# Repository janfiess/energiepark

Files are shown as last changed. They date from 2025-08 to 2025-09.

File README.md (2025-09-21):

# Energiepark Grischa

## Kopfhörerstationen

### MC -> TouchDesigner

Play/pause Audio 

* MQTT Topic: holz/player/audio/1     Payload: play oder pause
* MQTT Topic: holz/player/audio/2     Payload: play oder pause
* MQTT Topic: holz/player/audio/3     Payload: play oder pause
* MQTT Topic: holz/player/audio/4     Payload: play oder pause
* MQTT Topic: holz/player/audio/5     Payload: play oder pause
* MQTT Topic: holz/player/audio/6     Payload: play oder pause

TouchDesigner -> MC

### Drive LED-Ring sections (12 LEDs):

* MQTT Topic: holz/ledring/numsections/1     Payload: 0 - 12
* MQTT Topic: holz/ledring/numsections/2     Payload: 0 - 12
* MQTT Topic: holz/ledring/numsections/3     Payload: 0 - 12
* MQTT Topic: holz/ledring/numsections/4     Payload: 0 - 12
* MQTT Topic: holz/ledring/numsections/5     Payload: 0 - 12
* MQTT Topic: holz/ledring/numsections/6     Payload: 0 - 12

Notification when track ended, wenn der Kopfhörer eingehängt wurde (denn RFID Tag erkannt wurde):

* MQTT Topic:  ledring/state/1          Payload: leds_idle
* MQTT Topic:  ledring/state/2          Payload: leds_idle
* MQTT Topic:  ledring/state/3          Payload: leds_idle
* MQTT Topic:  ledring/state/4          Payload: leds_idle
* MQTT Topic:  ledring/state/5          Payload: leds_idle
* MQTT Topic:  ledring/state/6          Payload: leds_idle

RFID Tags:
Jeder Kopfhörer ist mit 3 RFID Tags ausgestattet. Mindestens einer muss erkannt werden.

Kopfhörer 1:
* 14AA77D6 (K1A)
* A44347D0 (K1B)
* ....

Kopfhörer 2:
* 241A5FD6 (K2A)
* F40735D6 (K2B)
* ...

Kopfhörer 3:
* 94326BD6 (K3A)
* 271652FA (K3B)
* ...

Kopfhörer 4:
* 74A06BD6 (K4A)
* 27E655FA (K4B)
* ...

Kopfhörer 5:
* 747E6AD6 (K5A) 
* 477251FA (K5B)
* ...

Kopfhörer 6:
* C4B86DD6 (K6A)
* D7091DFA (K6B)
* ...

## RFID-Scan-Station

### MQTT: MC -> TouchDesigner

Topic: holz/rfid     Payload: [id]

### RFID Tags:

Objekt 1 (Kohle klein):
* A5377800 (S1A)
* 1B047A00 (S1B)

Objekt 2 (Kohle gross):
* 57DD7900 (S2A)
* FA9B7800 (S2B)

Objekt 3 (Heizöl):
* 01107B00 (S3A)
* C6937A00 (S3B)

Objekt 4 (Holz):
* 67BC7A00 (S4A)
* E5BA7800 (S4B)

Objekt 5 (tbd):
* 492F7A00 (S5A)
* 35727D00 (S5B)

## LED-Strip

Bespielung via Art-Net.
Adresse LED-Controller (ebenfalls im Switch-Netzwerk): 	192.168.50.195

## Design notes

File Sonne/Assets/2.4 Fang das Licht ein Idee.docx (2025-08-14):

# 2.4 Fang das Licht ein – interaktive Station

Ausgangslage:

PV-Panel:

Grösse PV-Panel: 120cm x 55 cm = 0,66 m²

Strahlungsstärke: 1000 W/m^2

Wirkungsgrad: 20 %

Formel: Stärke x Grösse x Wirkungsgrad x Zeit (h) = Strom

1000 x 0.66 x 0.2 x 1h = 0.132 kWh (Maximum)

💡 LED Lampe 5 Watt für 470 lm

Frage:

Wie lange kann eine LED-Lampe brennen, wenn die Sonne 1 Stunde bei aktueller Neigung des PV-Panels Licht einfängt?

Auf der Grafik verändern sich die Anzeige immer interaktiv zur Bewegung des Panels:

1 aktuelle Stromproduktion
2 Effizienz
3 Farbige Skala
4 Anzahl Stunden

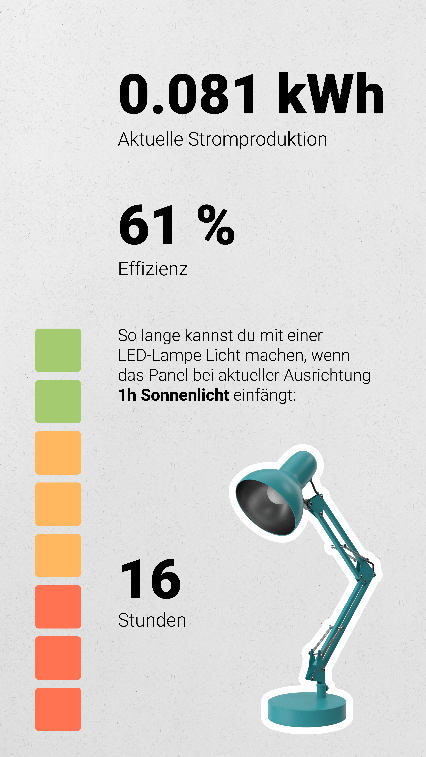
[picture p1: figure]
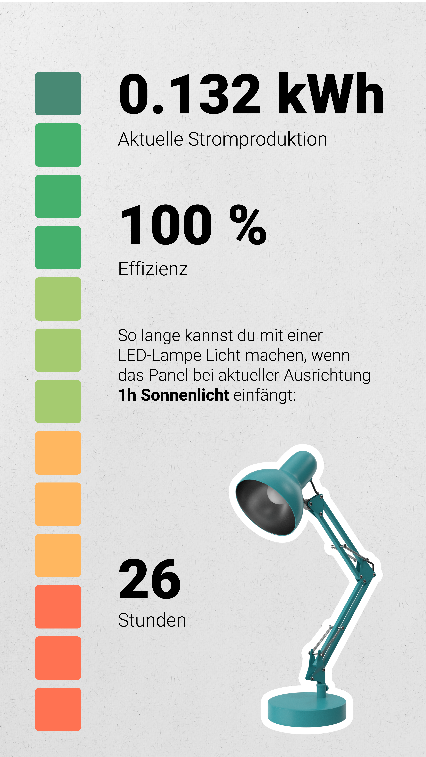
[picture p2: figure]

Grafik 1:

Anzeige bei mittel optimaler Ausrichtung des PV-Panels

Grafik 2:

Anzeige, bei perfekter Ausrichtung des PV-Panels

Abstufungen der Skala

kWh Stunden

0.010 2

0.020 4

0.030 6

0.040 8

0.050 10

0.060 12

0.070 14

0.080 16

0.090 18

0.100 20

0.110 22

0.120 24

0.130 26

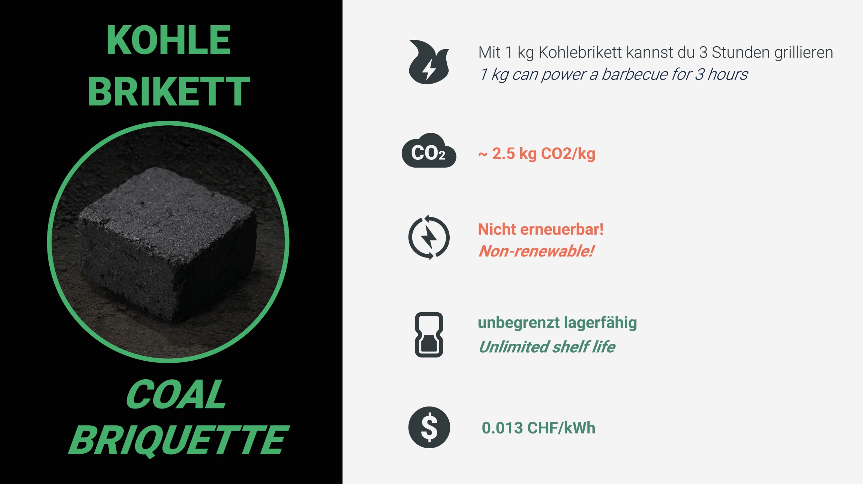
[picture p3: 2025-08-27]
Holz/Assets/RFID-Scanner Watt steckt da drin/1.2_Watt_steckt_da_drin-Kohle.jpeg

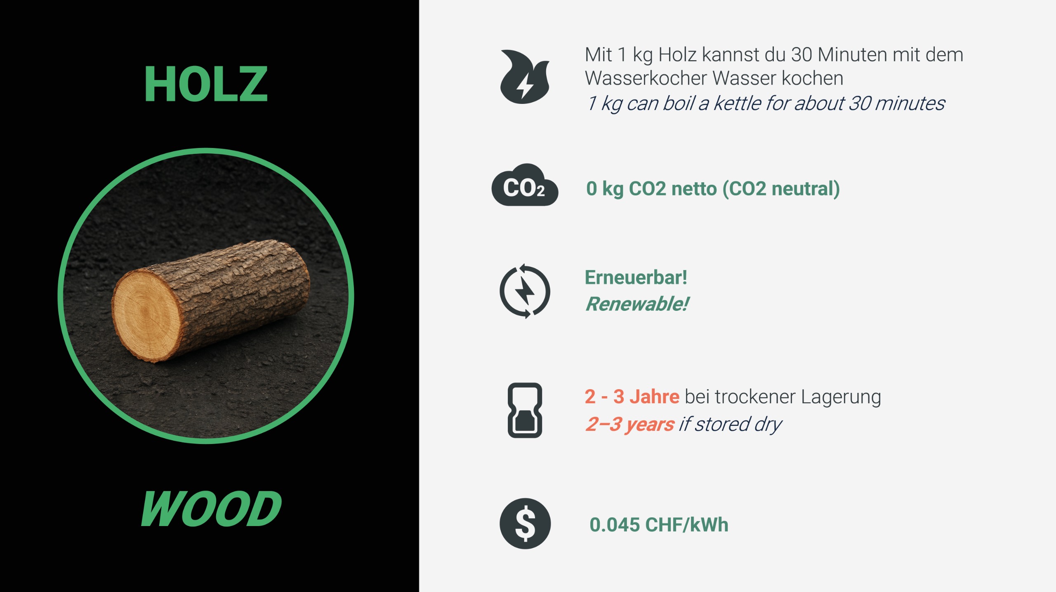
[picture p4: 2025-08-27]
Holz/Assets/RFID-Scanner Watt steckt da drin/1.2_Watt_steckt_da_drin-Holz.jpeg

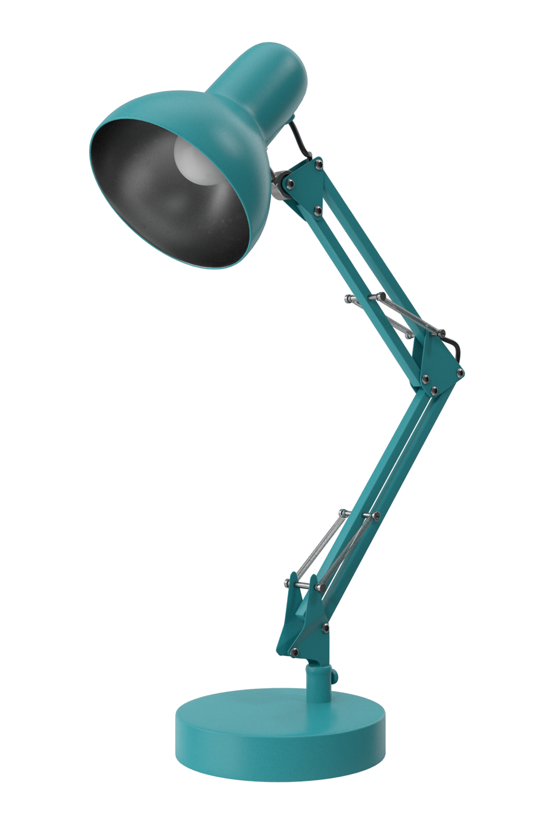
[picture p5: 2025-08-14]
Sonne/Assets/Bürotischlampe.png

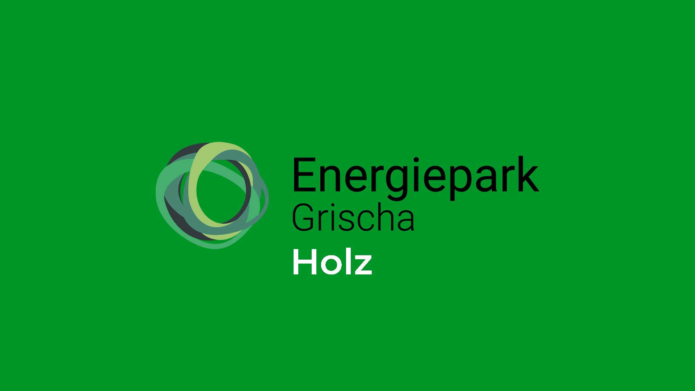
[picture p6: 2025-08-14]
Holz/Assets/Desktop.jpg

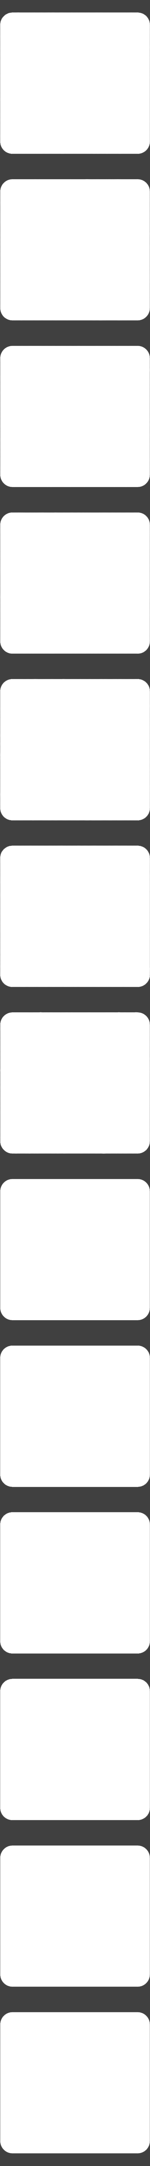
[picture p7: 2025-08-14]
Sonne/Assets/Balken.png

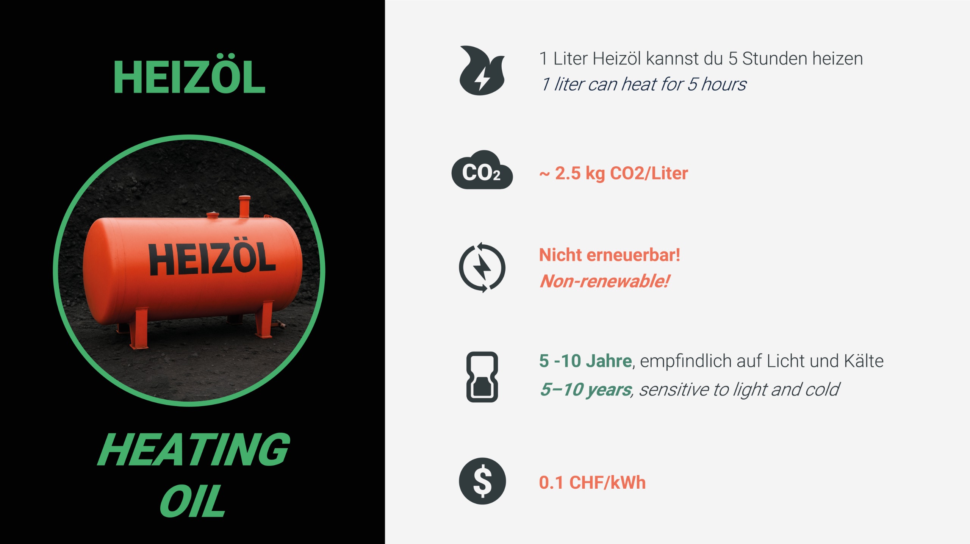
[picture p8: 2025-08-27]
Holz/Assets/RFID-Scanner Watt steckt da drin/1.2_Watt_steckt_da_drin-Heizoel.jpeg

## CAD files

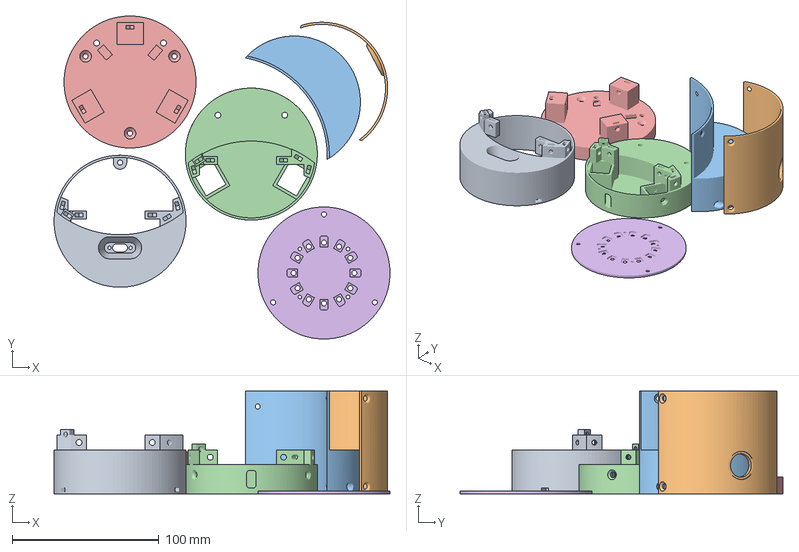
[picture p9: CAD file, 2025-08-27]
Holz/Dependencies/Headphone_Station/CAD/Kopfhörerständer.3mf
229.0 x 220.2 x 70.0 mm
TOF-Body.stl
Deckel unter PCB.stl
Deckel über PCB.stl
Basisplatte.stl
Adapterplatte.stl
LED-Ring.stl

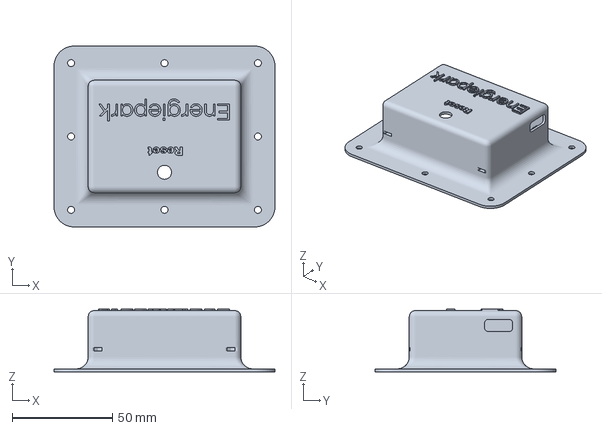
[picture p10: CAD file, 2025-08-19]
Sonne/Dependencies/mc/Gehäuse/Lagesensor Case v2.3mf
110.0 x 90.0 x 31.3 mm

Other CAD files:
Holz/Dependencies/Headphone_Station/CAD/Kopfhörerständer.f3d
Holz/Dependencies/Headphone_Station/CAD/RFID Scanner und Tags.f3d
Sonne/Dependencies/mc/Gehäuse/Lagesensor Case v2.f3d
Sonne/Dependencies/mc/Gehäuse/Lagesensor Case v2.stl

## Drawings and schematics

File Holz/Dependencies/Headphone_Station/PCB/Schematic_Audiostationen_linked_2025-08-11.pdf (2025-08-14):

A | A

1

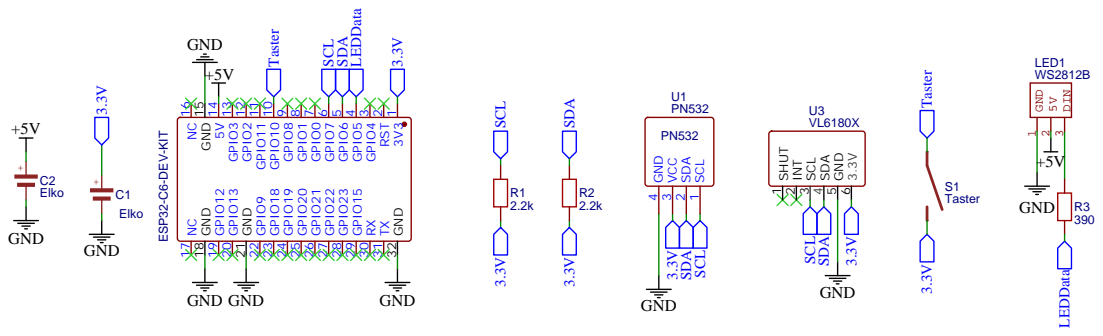
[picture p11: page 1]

9 GPIO10 10 GPIO11 11 GPIO2 12 GPIO3 13 5V 14 GND 15 NC 16 NC 17 GND 18 GPIO12 19 GPIO13 20 GND 21 GPIO9 22 GPIO18 23 GPIO19 24

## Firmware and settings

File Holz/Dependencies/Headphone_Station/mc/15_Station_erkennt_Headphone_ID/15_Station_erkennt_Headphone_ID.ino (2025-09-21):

/*****************************************************************
 * Lese RFID / NFC Sensor (PN532) und teile TouchDesigner (über MQTT mit, ob ein Kopfhörer (mit RFID-Tags) in der Nähe ist
 * Der Code benachrichtigt nur, wann die "Session" (erkannt oder nicht erkannt) beginnt und wann sie endet.
 * Entprellung: Um Fehlimpulse zu vermeiden wird der Wert zunächst mit den letzten Werten verglichen. Wenn der Wert konstant bleibt, wird der Zustand als "geändert" anerkannt.
 * Wenn kein bekanntes Netzwerk gefunden wird, startet der ESP einen Access Point. Wenn man dieses WLAN Netzwerk am Computer / Smartphone auswählt,
 * kommt man per Captive WLAN auf eine Setup-Website (ein DNS-Server leitet alle Domains auf die ESP-IP 192.168.4.1 um). 
 * Dort können SSID und PW des WLAN-Netzwerks eingegeben werden, mit dem man sich verbinden mag.
 * Diese Setup-Page ist auch ohne AP-Mode über die IP Adresse des ESP im Browser verfügbar.
 * Die Daten aus dem Web-Formular werden im Flash Speicher des ESP gespeichert, damit er sich diese Info beim nächsten Start direkt abrufen kann 
 * und sich z. B. ohne Nachfrage mit einem Netzwerk verbinden kann.
 *
 * Anschluss:
 *
 * RFID/NFC: PN532, TOF: VL6180X ( * turn on I2C mode by switching physical switches on the PN532 to 1 / 0 (I2C))
 * RFID/NFC bzw. TOF: SDA <-> ESP32-C6: GPIO 6
 * RFID/NFC bzw. TOF: SCL <-> ESP32-C6: GPIO 7
 * RFID/NFC bzw. TOF: Vcc <-> ESP32-C6: 3.3V
 * RFID/NFC bzw. TOF: GND <-> ESP32-C6: GND

 * LED-Ring 
 * WS2812B-Ring: Data In  <->  ESP32-C6: GPIO 5
 * WS2812B-Ring: +5V/Vcc  <->  ESP32-C6: 5V
 * WS2812B-Ring: GND      <->  ESP32-C6: GND

 * Taster
 * Taster Pin 1   <->  ESP32-C6: 3.3V
 * Taster Pin 2   <->  ESP32-C6: GPIO 10
 *
 * Installiere folgende Libraries: 
 * -  "Adafruit_PN532" von Adafruit
 * -  "MQTT" von Joel Gaehwiler
 * -  "Adafruit_NeoPixel" von Adafruit
 *
******************************************************************/


#include <WiFi.h>
#include <WebServer.h>
#include <Preferences.h>
#include <DNSServer.h>                                                 // für Captive Portal ("Hotel-WLAN-Start-Screen")
#include <MQTT.h>
#include <Wire.h>                                                      // I2C (so kommuniziert z. B. der NFC / RFID-Reader)
#include <Adafruit_PN532.h>                                            // NFC Reader
#include "esp_log.h"                                                   // nicht die Konsole voll schreiben, wenn es ab und zu einen I2C Nack gibt
#include <Adafruit_NeoPixel.h>                                         // LED-Ring


Preferences preferences;
String id_station;                              // id der Kopfhörerstation 1 - 6
int current_headphone_id;                       // 1 - 6


// Variablen für die Ziel-WLAN-Daten - wird auf der Setup-Website des ESP-Access Points eingegeben.
String targetSSID = "";                                                // "Energiepark Technik", "tinkergarden", "LinusFetzMusikGast"
String targetPassword = "";                                            // "Energiepark2025.8", "strenggeheim", "linusfetzgast"
WiFiClient wificlient;


// Server für Setup-Page
bool apMode = false;    
WebServer server(80);                                                  // Lokaler Webserver auf Port 80, um Setup-Seite im Browser bereitzustellen
DNSServer dnsServer;                                                   // für Captive Portal
const byte DNS_PORT = 53;                                              // für Captive Portal.  // DNS-Server: Alle Anfragen -> ESP32
  

// MQTT
String mqtt_broker = "";                                                          // "broker.emqx.io", "192.168.0.60", "test.mosquitto.org", "broker.hivemq.com"
String MQTT_PUBLISH_TOPIC_AUDIO_PRE = "holz/player/audio/";                       // Topics.  -   Diese werden für Subscribing und Publishing genutzt
String MQTT_PUBLISH_TOPIC_AUDIO;                                                  // je nach Kopfhörer kann die id wechseln, z. B.  "holz/ledring/numsections/1"
String MQTT_SUBSCRIBE_TOPIC_SECTIONS_LEDRING = "holz/ledring/numsections/#";      // Beispiel: "holz/ledring/numsections/1"   |  Payload: 0 - 12
String MQTT_SUBSCRIBE_TOPIC_TRACK_STATE = "holz/ledring/state/#";                 // message when audio track ended -> Payload: "leds_idle"
String subscribe_topics[10];                                                                       // Array der zu abonnierenden Topics (hier nur eines, aber erweiterbar)
MQTTClient mqttclient;


// I2C Pins definieren
#define SDA_PIN 6
#define SCL_PIN 7


// NFC Reader
// IRQ und RESET Pins definieren – werden vom PN532-Modul NICHT verwendet bei I2C, aber Bibliothek erwartet sie
#define PN532_IRQ   (2)
#define PN532_RESET (3)
Adafruit_PN532 nfc(PN532_IRQ, PN532_RESET, &Wire);                     // Konstruktor mit IRQ, RESET und Wire

String target_rfid_1[3];
String target_rfid_2[3];
String target_rfid_3[3];
String target_rfid_4[3];
String target_rfid_5[3];
String target_rfid_6[3];



const uint8_t NFC_TARGET_UID_LENGTH = 7;


// Statusvariablen für die verbesserte Erkennung                       // Merkt sich, ob der TARGET_UID-Tag aktuell als "anwesend" gilt // Wert ist bereits entprellt
int nfc_presentConfirmCounter = 0;                                     // Zählt aufeinanderfolgende erfolgreiche Lesungen des TARGET_UID
int nfc_absentConfirmCounter = 0;                                      // Zählt aufeinanderfolgende fehlgeschlagene Lesungen (Tag nicht da)

const int NFC_CONFIRM_PRESENT_THRESHOLD = 3;                           // Der Tag muss X-mal hintereinander korrekt gelesen werden, um als "anwesend" zu gelten.
const int NFC_CONFIRM_ABSENT_THRESHOLD = 5;                            // Der Tag muss X-mal hintereinander NICHT gelesen werden, um als "entfernt" zu gelten.

uint8_t nfc_uid[7];                                                    // Buffer zum Speichern der UID
uint8_t nfc_uidLength;                                                 // Länge der UID
bool nfc_tag_erkannt;                                                  // in dieser Variable wird gespeichert, ob irgendein NFC Tag erkannt wurde
bool nfc_isTargetTag;                                                  // handelt es sich bei dem erkannten NFC Tag wirklich um den gewünschten? 


// LED-Ring
#define LED_PIN 5
#define NUM_PIXELS 12
#define DELAYVAL 500
#define LED_BRIGHTNESS 50
Adafruit_NeoPixel strip = Adafruit_NeoPixel(NUM_PIXELS, LED_PIN, NEO_GRB + NEO_KHZ800);


// Taster
#define TASTER_PIN 10
int buttonState = 0;         
int prev_buttonState = 0;


// allgemein
bool is_object_detected;                                               // diese Variable is nur dann true oder false, wenn alle Sensoren den Wert true bzw. false ausgeben
bool prev_is_object_detected;


// Funktionsprototypen
void connectWiFi();
void connectMQTT();
void start_webserver();
void start_access_point();
void load_setup_data();                                                // Gespeicherte Setup-Daten (Preferences -> persistent in Flash-Speicher) laden, falls bereits per Setup-Seite festgelegt
void mqtt_messageReceived(String& topic, String& payload);
void send_website_save();
void save_settings();
void send_website_settings();
void init_nfc();
void read_nfc();
void read_button();
void init_led_ring();











void setup() {
  Serial.begin(115200);
  delay(1000);
  Serial.println("Kopfhörer-Station startet...");
  load_setup_data();                               // Gespeicherte Setup-Daten (Preferences -> persistent in Flash-Speicher) laden, falls bereits per Setup-Seite festgelegt
  connectWiFi();

  if (WiFi.status() == WL_CONNECTED) {             // MQTT Client initialisieren und Callback setzen 
    mqttclient.begin(mqtt_broker.c_str(), wificlient);
    connectMQTT();
    mqttclient.onMessage(mqtt_messageReceived);
  } 
  else start_access_point();                       // Falls keine Verbindung zu einem gespeicherten Netzwerk zustande kommt, starte den Access Point
    
  start_webserver();                               // Webserver starten, unabhängig von STA oder AP


  // I2C
  esp_log_set_vprintf([](const char *fmt, va_list args) -> int {
    (void)fmt;   // ignore
    (void)args;  // ignore
    return 0;    // nichts ausgeben
  });

  Wire.begin(SDA_PIN, SCL_PIN);   // Wire starten mit den benutzerdefinierten I2C Pins
  init_nfc();                     // NFC Sensor


  // Init LED-Ring
  init_led_ring();


  // Init Taster
  pinMode(TASTER_PIN, INPUT_PULLDOWN);
  Serial.println("Setup abgeschlossen."); 
}




void loop() {
  dnsServer.processNextRequest();                // @neu für Captive Portal
  server.handleClient();
 
  // Nur im STA-Modus reconnecten!
  if (!apMode && targetSSID != "" && WiFi.status() != WL_CONNECTED) {
    Serial.println("Versuche Verbindung mit gespeicherten Daten...");
    connectWiFi();
    delay(5000);
  }
  
  // MQTT-Verbindung bei Verlust wiederherstellen
  if (!apMode) {
    mqttclient.loop();                                                    // MQTT Loop regelmässig aufrufen, um die Verbindung am Leben zu halten und Nachrichten zu empfangen  
    if (!mqttclient.connected()) {                                        // Überprüfen, ob die MQTT-Verbindung aktiv ist. Wenn nicht, versuchen wir uns neu zu verbinden.
      Serial.println("MQTT Verbindung verloren. Versuche Neuverbindung...");
      connectMQTT();
    }
  }

  // RFID / NFC
  read_nfc();                                                             // get NFC "button" state


  if(is_object_detected != prev_is_object_detected) {
    prev_is_object_detected = is_object_detected;
    MQTT_PUBLISH_TOPIC_AUDIO = MQTT_PUBLISH_TOPIC_AUDIO_PRE + String(current_headphone_id);
    
    if(is_object_detected) {
      String publishPayload = "pause";
      Serial.printf("--> Publishing: Topic: %s, Payload: %s\n", MQTT_PUBLISH_TOPIC_AUDIO.c_str(), publishPayload);
      if(mqttclient.connected()) {
        mqttclient.publish(MQTT_PUBLISH_TOPIC_AUDIO.c_str(), publishPayload);
      }

      // LED Ring in Idle Mode
      strip.clear();
      for(int i=0; i<12; i++) {                                        // für jeden einzelnen Pixel - in der Schleife    
        strip.setPixelColor(i, strip.Color(20, 40, 0));                // Werte: 0 - 255
      }
      strip.show();                                                    // sende den aktualisierten Pixel an den LED-Ring
 
    } else {
      String publishPayload = "play";
      Serial.printf("--> Publishing: Topic: %s, Payload: %s\n", MQTT_PUBLISH_TOPIC_AUDIO.c_str(), publishPayload);
      if(mqttclient.connected()) {
        mqttclient.publish(MQTT_PUBLISH_TOPIC_AUDIO.c_str(), publishPayload);
      }
    }
  }
  
  read_button();                                                          // Alterative: Taster statt RFID-Erkennung
  delay(100);                                                             // kurze Pause, entlastet den Prozessor
}



/****************************************************************************************************
 * WLAN-Verbindung herstellen   // wird in setup gerufen und wenn Verbindung verloren geht
 ****************************************************************************************************/ 

void connectWiFi() {
  // Versuche, mit den gespeicherten Daten zu verbinden
  if (targetSSID != "") {
    Serial.printf("Versuche Verbindung mit gespeichertem WLAN: '%s' (PW: '%s')\n", targetSSID.c_str(), targetPassword.c_str());
    WiFi.begin(targetSSID.c_str(), targetPassword.c_str());
    unsigned long startAttemptTime = millis();

    // Versuche 10 Sekunden lang
    while (WiFi.status() != WL_CONNECTED && millis() - startAttemptTime < 10000) {
      delay(500);
      Serial.print(".");
    }
    Serial.println();
  }

  // Überprüfe den WLAN-Status und handle entsprechend
  if (WiFi.status() == WL_CONNECTED) {
    Serial.printf("Erfolgreich verbunden: SSID: %s, IP-Adresse: %s \n", targetSSID.c_str(), WiFi.localIP().toString().c_str());
    apMode = false;
  }
}



/****************************************************************************************************
 * Gespeicherte Setup-Daten (Preferences -> persistent in Flash-Speicher) laden, falls bereits per Setup-Seite festgelegt
 ****************************************************************************************************/ 
  
void load_setup_data(){
  preferences.begin("wifi", true);
  targetSSID = preferences.getString("ssid", "");
  targetPassword = preferences.getString("password", "").c_str();
  mqtt_broker = preferences.getString("mqtt_broker", "").c_str();

  target_rfid_1[0] = preferences.getString("target_rfid_1a", "");
  target_rfid_1[1] = preferences.getString("target_rfid_1b", "");
  target_rfid_1[2] = preferences.getString("target_rfid_1c", "");

  target_rfid_2[0] = preferences.getString("target_rfid_2a", "");
  target_rfid_2[1] = preferences.getString("target_rfid_2b", "");
  target_rfid_2[2] = preferences.getString("target_rfid_2c", "");

  target_rfid_3[0] = preferences.getString("target_rfid_3a", "");
  target_rfid_3[1] = preferences.getString("target_rfid_3b", "");
  target_rfid_3[2] = preferences.getString("target_rfid_3c", "");

  target_rfid_4[0] = preferences.getString("target_rfid_4a", "");
  target_rfid_4[1] = preferences.getString("target_rfid_4b", "");
  target_rfid_4[2] = preferences.getString("target_rfid_4c", "");

  target_rfid_5[0] = preferences.getString("target_rfid_5a", "");
  target_rfid_5[1] = preferences.getString("target_rfid_5b", "");
  target_rfid_5[2] = preferences.getString("target_rfid_5c", "");

  target_rfid_6[0] = preferences.getString("target_rfid_6a", "");
  target_rfid_6[1] = preferences.getString("target_rfid_6b", "");
  target_rfid_6[2] = preferences.getString("target_rfid_6c", "");

  id_station = preferences.getString("id_station", "9");
  preferences.end();
  Serial.printf("Found in Flash: SSID: %s, Passwort: %s \n", targetSSID.c_str(), targetPassword.c_str());
}



/****************************************************************************************************
 * MQTT-Verbindung herstellen
 ****************************************************************************************************/ 

void connectMQTT() {                                                                        // Diese Funktion kümmert sich nur noch um den eigentlichen Verbindungsaufbau und das Abonnement.
  Serial.printf("Verbinde mit MQTT Broker: %s\n", mqtt_broker);
  int attempts = 0;
  // Versuche, eine Verbindung herzustellen, bis sie erfolgreich ist
  while (!mqttclient.connect(id_station.c_str())) {                                         // Optional: Mit Benutzername/Passwort: mqttclient.connect(mqtt_client_id, "username", "password"). ->  -> username und passwort sind oft jeweils "public"
    Serial.println("Fehler beim Verbinden mit MQTT-Broker. Neuer Versuch in 2 Sekunden...");
    attempts++;
    if(attempts > 10){
      Serial.println("\nMQTT Verbindung fehlgeschlagen! Neustart ...");
      ESP.restart();   // Neustart auslösen
    }
    delay(2000);
  }
  
  Serial.println("Verbunden mit MQTT-Broker");

  mqttclient.subscribe(MQTT_SUBSCRIBE_TOPIC_SECTIONS_LEDRING);
  Serial.printf("Abonniert Topic: %s\n", MQTT_SUBSCRIBE_TOPIC_SECTIONS_LEDRING.c_str());          // Bestätigung des Abonnements

  mqttclient.subscribe(MQTT_SUBSCRIBE_TOPIC_TRACK_STATE);
  Serial.printf("Abonniert Topic: %s\n", MQTT_SUBSCRIBE_TOPIC_TRACK_STATE.c_str());  
}



/****************************************
 * MQTT Callback für eingehende Nachrichten
 ****************************************/

void mqtt_messageReceived(String& topic, String& payload) {
  Serial.printf("<-- MQTT msg empfangen: Topic: %s, Payload: %s\n", topic.c_str(), payload.c_str());
  


  String id_from_incoming_topic = get_id_from_incoming_topic(topic);
  // Serial.printf("id_station: %s \n", id_station);
  if(id_from_incoming_topic != String(current_headphone_id)){
    Serial.println("Diese Nachricht betrifft nicht diese Station");
    return;
  } 



  if (topic.startsWith("holz/ledring/numsections")) {
    int numLedsToLight = payload.toInt();

    // LED-Ring bespielen
    strip.clear();
    for(int i=0; i<numLedsToLight; i++) {                   // für jeden einzelnen Pixel - in der Schleife
      strip.setPixelColor(i, strip.Color(128, 255, 0));     // Werte: 0 - 255
    }
    strip.show();                                           // sende den aktualisierten Pixel an den LED-Ring
  }






  if (topic.startsWith("holz/ledring/state")) {
    if(payload == "leds_idle"){
      strip.clear();
      for(int i=0; i<12; i++) {                             // für jeden einzelnen Pixel - in der Schleife    
        strip.setPixelColor(i, strip.Color(20, 40, 0));     // Werte: 0 - 255
      }
      strip.show();                                         // sende den aktualisierten Pixel an den LED-Ring
    }
  }
}




// called in mqtt_messageReceived()
String get_id_from_incoming_topic(String topic){
// Finde die Position des letzten Schrägstrichs
    int lastSlashIndex = topic.lastIndexOf('/');
    // Überprüfe, ob ein Schrägstrich gefunden wurde
    if (lastSlashIndex != -1) {
      // Extrahiere den Teil des Strings nach dem letzten Schrägstrich
      String deviceIdString = topic.substring(lastSlashIndex + 1);


      // Gib das Ergebnis aus
      // Wandle den extrahierten String in einen Integer um
      String id_from_incoming_message = deviceIdString;
      Serial.printf("id_from_incoming_message: %s \n", id_from_incoming_message);
      // Serial.println(id_from_incoming_message); // Ausgabe: 1
      return id_from_incoming_message;
    }
  }






/****************************************************************************************************
 * Webserver starten, unabhängig von STA oder AP
 ****************************************************************************************************/ 

void start_webserver(){
  server.on("/", send_website_settings);
  server.on("/save", save_settings);
  server.onNotFound(send_website_settings);
  server.begin();

  if (apMode) {
    Serial.println("Webserver + DNS gestartet (Captive Portal aktiv)");
  } else {
    Serial.println("Webserver gestartet (STA-Modus, erreichbar über lokale IP)");
  }
}



/****************************************************************************************************
 * Access Point (AP) starten, falls sich der ESP mit keinem WLAN Netzwerk verbinden kann
 ****************************************************************************************************/ 

void start_access_point(){
  Serial.println("Keine Verbindung, starte Access Point...");
  WiFi.softAP("Headphone Setup");  // offen, ohne Passwort

  IPAddress apIP = WiFi.softAPIP();
  Serial.print("AP gestartet, IP: ");
  Serial.println(apIP);

  // DNS-Server: Alle Domains -> ESP
  dnsServer.start(DNS_PORT, "*", apIP);

  apMode = true;   // wir sind im AP-Modus
}



/*********************************************************************
 * Websites
 *********************************************************************/
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

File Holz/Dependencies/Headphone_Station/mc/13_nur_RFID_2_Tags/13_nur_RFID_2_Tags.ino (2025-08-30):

/*****************************************************************
 * Beispiel: WLAN + MQTT + TOF-Schalter: Publish / Receive
 * Read PN532 sensor via I2C and publish to MQTT broker whether an object is close to the Reader or not.
 * In der Konsole wird nur geprintet, wann die "Session" beginnt und wann sie endet.
 * Für etwas Toleranz wird der Wert mit den letzten Werten verglichen. Um Fehlimpulse zu vermeiden, wird die Console erst beschrieben,
 * sobald die aktuelle Messung mit den letzten paar Messungen übereinstimmt.
 *
 * turn on I2C mode by switching physical switches on the PN532 to 1 / 0 (I2C)
 * Anschluss:

 * RFID/NFC: PN532, TOF: VL6180X
 * RFID/NFC bzw. TOF: SDA <-> ESP32-C6: GPIO 6
 * RFID/NFC bzw. TOF: SCL <-> ESP32-C6: GPIO 7
 * RFID/NFC bzw. TOF: Vcc <-> ESP32-C6: 3.3V
 * RFID/NFC bzw. TOF: GND <-> ESP32-C6: GND

 * LED-Ring 
 * WS2812B-Ring: Data In  <->  ESP32-C6: GPIO 5
 * WS2812B-Ring: +5V/Vcc  <->  ESP32-C6: 5V
 * WS2812B-Ring: GND      <->  ESP32-C6: GND

 * Taster
 * Taster Pin 1   <->  ESP32-C6: 3.3V
 * Taster Pin 2   <->  ESP32-C6: GPIO 10
 *
 * Installiere folgende Libraries: 
 * -  "Adafruit_PN532" von Adafruit
 * -  "MQTT" von Joel Gaehwiler
 * -  "Adafruit_NeoPixel" von Adafruit
******************************************************************/


#include <WiFi.h>
#include <MQTT.h>
#include <Wire.h>                                                      // I2C
// #include "Adafruit_VL6180X.h"
#include <Adafruit_PN532.h>                                            // NFC Reader
#include "esp_log.h" 
#include <Adafruit_NeoPixel.h>


// WLAN und MQTT Einstellungen
// const char* ssid = "Energiepark Technik";                                // @todo: add your wifi name "FRITZ!Box 6690 TA"
const char* ssid = "tinkergarden";                                // @todo: add your wifi name "FRITZ!Box 6690 TA"
// const char* ssid = "LinusFetzMusikGast";                                // @todo: add your wifi name "FRITZ!Box 6690 TA"
// const char* pass = "Energiepark2025.8";                             // @todo: add your wifi pw, "79854308499311013585"
const char* pass = "strenggeheim";                             // @todo: add your wifi pw, "79854308499311013585"
// const char* pass = "linusfetzgast";                             // @todo: add your wifi pw, "79854308499311013585"
// const char* mqtt_broker = "192.168.178.25";                            // "broker.emqx.io", "192.168.0.80"
const char* mqtt_broker = "192.168.0.60";                            // "broker.emqx.io", "192.168.0.80"
// const char* mqtt_broker = "broker.hivemq.com";                            // "broker.emqx.io", "192.168.0.80", "test.mosquitto.org", "broker.hivemq.com"
const char* mqtt_client_id = "headphone_station_audio1de";

const char* MQTT_PUBLISH_TOPIC_AUDIO = "holz/player/audio1de";                    // Topics.  -   Diese werden für Subscribing und Publishing genutzt
const char* MQTT_SUBSCRIBE_TOPIC_SECTIONS_LEDRING = "holz/ledring_audio1de/numsections";      // Payload: 0 - 12
const char* MQTT_SUBSCRIBE_TOPIC_TRACK_STATE = "holz/ledring_audio1de/state"; 
const char* subscribe_topics[] = { MQTT_SUBSCRIBE_TOPIC_SECTIONS_LEDRING, MQTT_SUBSCRIBE_TOPIC_TRACK_STATE};         // Array der zu abonnierenden Topics (hier nur eines, aber erweiterbar)

WiFiClient wificlient;
MQTTClient mqttclient;




// I2C Pins definieren
#define SDA_PIN 6
#define SCL_PIN 7



// TOF Distanzsensor

/*
Adafruit_VL6180X tof = Adafruit_VL6180X();
int tof_maxdistance = 2;                                                // 30 ~ 40mm -> Sensor misst ab ca 10mm

// --- Globale Variablen für die Zustandsverwaltung ---
bool tof_objectDetected_temp = false;                                    // Aktueller Zustand (ohne Entprellung)
bool tof_objectDetected = false;                                         // Endgültiger Zustand (nach Entprellung) -> Wert gilt als endgültig, sobald mehrmals derselbe Wert erkannt wurde

// Array zum Speichern der letzten Zustände für die Entprellung
const int tof_toleranz_entprellung = 5;
bool tof_prevStates[tof_toleranz_entprellung]; 
int tof_state_index = 0;                                                 // Index für das Array
int tof_timestamp_prev_detected = 0;

*/


// NFC Reader

// IRQ und RESET Pins definieren – werden vom PN532-Modul NICHT verwendet bei I2C, aber Bibliothek erwartet sie
#define PN532_IRQ   (2)
#define PN532_RESET (3)

// Konstruktor mit IRQ, RESET und Wire
Adafruit_PN532 nfc(PN532_IRQ, PN532_RESET, &Wire);

// Ziel-UID definieren (7 Bytes)
// const uint8_t TARGET_UID[] = { 0xFF, 0x0F, 0x17, 0xE9, 0x3F, 0x00, 0x00 };
String target_id_1 = "14AA77D6";
String target_id_2 = "A44347D0";
const uint8_t NFC_TARGET_UID_LENGTH = 7;

// --- Statusvariablen für die verbesserte Erkennung ---
// bool nfc_tagCurrentlyPresent = false;                                  // Merkt sich, ob der TARGET_UID-Tag aktuell als "anwesend" gilt // Wert ist bereits entprellt
int nfc_presentConfirmCounter = 0;                                     // Zählt aufeinanderfolgende erfolgreiche Lesungen des TARGET_UID
int nfc_absentConfirmCounter = 0;                                      // Zählt aufeinanderfolgende fehlgeschlagene Lesungen (Tag nicht da)

const int NFC_CONFIRM_PRESENT_THRESHOLD = 3;                           // Der Tag muss X-mal hintereinander korrekt gelesen werden, um als "anwesend" zu gelten.
const int NFC_CONFIRM_ABSENT_THRESHOLD = 5;                            // Der Tag muss X-mal hintereinander NICHT gelesen werden, um als "entfernt" zu gelten.

uint8_t nfc_uid[7];                                                    // Buffer zum Speichern der UID
uint8_t nfc_uidLength;                                                 // Länge der UID
bool nfc_tag_erkannt;                                                  // in dieser Variable wird gespeichert, ob irgendein NFC Tag erkannt wurde
bool nfc_isTargetTag;                                                  // handelt es sich bei dem erkannten NFC Tag wirklich um den gewünschten? 


// LED-Ring


#define LED_PIN 5
#define NUM_PIXELS 12
#define DELAYVAL 500
#define LED_BRIGHTNESS 50

Adafruit_NeoPixel strip = Adafruit_NeoPixel(NUM_PIXELS, LED_PIN, NEO_GRB + NEO_KHZ800);


// Taster

#define TASTER_PIN 10
int buttonState = 0;         
int prev_buttonState = 0;


// allgemein

bool is_object_detected;                                               // diese Variable is nur dann true oder false, wenn alle Sensoren den Wert true bzw. false ausgeben
bool prev_is_object_detected;







// Funktionsprototypen
void connectWiFi();
void connectMQTT();
void mqtt_messageReceived(String& topic, String& payload);
// void init_tof();
// void read_tof();
void init_nfc();
void read_nfc();
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

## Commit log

2025-08-01 wlan, mqtt, nfc
    [Steckplan.fzz]
2025-08-03 NFC Button per MQTT
2025-08-03 Werte des TOF Schalters per MQTT verschicken
2025-08-04 I2C Neck Issue
2025-08-11 pcb dateien
    [Drill_NPTH_Through.DRL, Drill_PTH_Through.DRL, Drill_PTH_Through_Via.DRL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]
2025-08-14 ufgruumt + Sonnengrafik nachbilden
    [Drill_NPTH_Through.DRL, Drill_PTH_Through.DRL, Drill_PTH_Through_Via.DRL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]
2025-08-15 Arduino Scripte für Lagesensor (MQTT) und RFID-Scanner (MQTT) - ungetestet so far
2025-08-18 ufgruumt und funktionierender RFID Scanner mit MQTT Kommunikation (sendet nur einmal, bis er mal zwischendurch entfernt wird)
2025-08-19 Sensorik Sonne überarbeiten
2025-08-19 Gehäuse Lagesensor
    [Lagesensor Case v2.3mf, Lagesensor Case v2.f3d, Lagesensor Case v2.stl]
2025-08-24 trying to solve i2c nack
    [Kopfhörerständer.3mf]
2025-08-24 i2c nack-müll zumindest mal versteckt in der konsole
2025-08-25 Button integrated
2025-08-26 content eingebunden in TD und MQTT notification when track ended
2025-08-27 cad models update
    [Kopfhörerständer.f3d, Lagesensor Case v2.f3d, RFID Scanner und Tags.f3d]
2025-08-27 integrated LEDs
2025-08-27 LED-Ring Bespielung
2025-08-28 nommal öpis am led ring ghänderet
2025-08-28 Firmware updates
    [Steckplan.fzz]
2025-09-04 leds gehen nicht mehr aus, wenn kopfhörer eingehängt wird
2025-09-21 Kopfhörer können jetzt in beliebige Stationen eingehängt werden und diese passen sich an die jew Kopfhörer an. MQTT Nachrichten und TD angepasst
    [Drill_NPTH_Through.DRL, Drill_PTH_Through.DRL, Drill_PTH_Through_Via.DRL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]
2025-09-26 code für die Stationen ohne Sensorik
2025-10-08 mqtt verbindung: messaages, loo für 5 und 6
